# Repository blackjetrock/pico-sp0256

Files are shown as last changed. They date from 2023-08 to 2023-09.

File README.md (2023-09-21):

# Rp2040 Emulation of the SP0256-AL2 IC

Despite the name, this projects does not use the RP Pico. It is a PCB that has the footprint of the 28pin SP0256-AL2 IC. It plugs in to the same footprint as the IC and performs the functions that the IC does. Well, some of them:

1) Has allophones of the SP0256-AL2 as audio samples
2) Responds to the ALD signal falliung edge, latches the allophone nyumber and plays it.
3) Drives the LRQ line

It does not:
1) Handle an external ROM
2) Handle the play allohone on address line going to 1 mode.
   
This version of the code and PCB is designed to replace an SP0256-AL2 based psion organiser II speech adapter. It will need testing and adjusting in other uses.
It should be treated as a work in progress.

This project builds on the work of two other projects the first is here:

https://github.com/ExtremeElectronics/SP0256-AL2-Pico-Emulation-Detail

and contains code that drives the PWM to generate the audio from the phoneme data which is at this project:

https://www.cpcwiki.eu/index.php/SP0256_Allophones

These two projects have been combined and then added to in order to do the emulation of the SP0256 IC itself, such that it can be placed into the footprint of one of those ICs.

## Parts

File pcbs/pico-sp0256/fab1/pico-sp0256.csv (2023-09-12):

Id | Designator | Package | Quantity | Designation | Supplier and ref
1 | R4,R3 | R_0805_2012Metric | 2 | 27R
2 | Y1 | ecx-32 | 1 | ABLS-12.000MHZ-B4-T
3 | U1 | DIP-28_W15.24mm | 1 | SP0256AL2
4 | D2,D1 | D_SOD-123 | 2 | D_Small
5 | U5 | RP2040-QFN-56-no_holes | 1 | RP2040
6 | U3 | SOT-223-3_TabPin2 | 1 | NCP1117-3.3_SOT223
7 | U2 | SOIC-8_5.23x5.23mm_P1.27mm | 1 | W25Q128JVS
8 | R2 | C_0402_1005Metric | 1 | 10k
9 | R1 | C_0402_1005Metric | 1 | 1k
10 | J2 | PinHeader_1x03_P2.54mm_Vertical | 1 | Conn_01x03_Female
11 | J1 | USB_Micro-B_GCT_USB3076-30-A | 1 | USB_B_Micro
12 | C12,C11,C9,C7,C6,C3 | C_0402_1005Metric | 6 | 100n
13 | C10,C8 | C_0402_1005Metric | 2 | 1u
14 | C5,C4 | C_0805_2012Metric | 2 | 10u
15 | C2,C1 | C_0402_1005Metric | 2 | 27p

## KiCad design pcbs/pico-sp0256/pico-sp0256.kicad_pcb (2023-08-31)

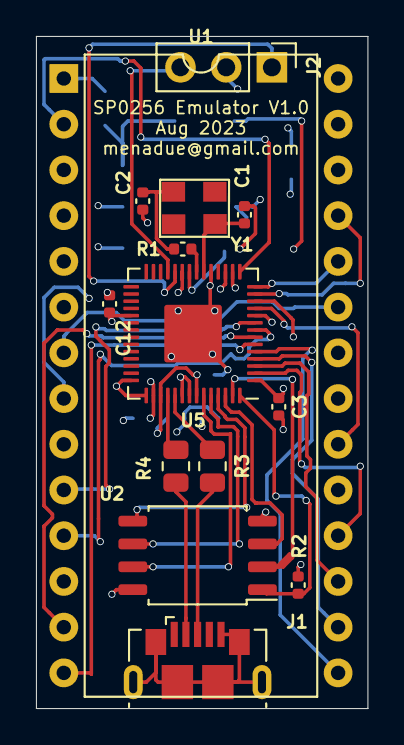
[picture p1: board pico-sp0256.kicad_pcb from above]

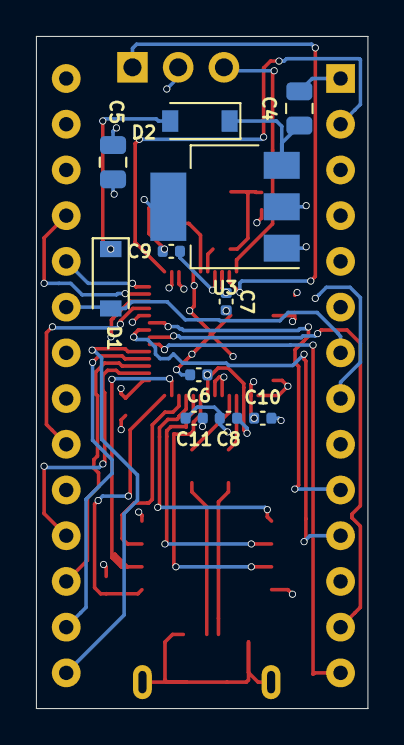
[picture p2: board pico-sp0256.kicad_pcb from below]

Board: 4 copper layers, 18.4 x 37.3 mm, 25 parts (11 on the bottom side), 36 nets.

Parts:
C1, C2: 27p; C_0402_1005Metric
C3, C6, C7, C9, C11, C12: 100n; C_0402_1005Metric
C4, C5: 10u; C_0805_2012Metric
C8, C10: 1u; C_0402_1005Metric
D1, D2: D_Small; D_SOD-123
J1: USB_B_Micro; USB_Micro-B_GCT_USB3076-30-A
J2: Conn_01x03_Female; PinHeader_1x03_P2.54mm_Vertical
R1: 1k; C_0402_1005Metric
R2: 10k; C_0402_1005Metric
R3, R4: 27R; R_0805_2012Metric
U1: SP0256AL2; DIP-28_W15.24mm
U2: W25Q128JVS; SOIC-8_5.23x5.23mm_P1.27mm
U3: NCP1117-3.3_SOT223; SOT-223-3_TabPin2
U5: RP2040; RP2040-QFN-56-no_holes
Y1: ABLS-12.000MHZ-B4-T; ecx-32

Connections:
+1V1: C6.1, C7.1, C8.1, U5.23, U5.45, U5.50
+3V3: C3.1, C5.1, C9.1, C10.1, C11.1, C12.1, R2.1, U2.8, U3.2, U5.1, U5.10, U5.22, U5.33, U5.42, U5.43, U5.44, U5.48, U5.49
GND: C1.2, C2.2, C3.2, C4.2, C5.2, C6.2, C7.2, C8.2, C9.2, C10.2, C11.2, C12.2, J1.5, J1.6, J2.2, U1.1, U2.4, U3.1, U5.19, U5.57
unnamed: C2.1, R1.2, Y1.2
unnamed: C4.1, D2.1, U3.3
unnamed: D1.1, D2.2
unnamed: J1.2, R4.2
unnamed: J1.3, R3.2
QSPI_SCLK: U2.6, U5.52
QSPI_SD0: U2.5, U5.53
QSPI_SD1: U2.2, U5.55
QSPI_SD2: U2.3, U5.54
QSPI_SD3: U2.7, U5.51
QSPI_SS: R2.2, U2.1, U5.56
SP_A1: U1.18, U5.2
SP_A2: U1.17, U5.3
SP_A3: U1.16, U5.4
SP_A4: U1.15, U5.5
SP_A5: U1.14, U5.6
SP_A6: U1.13, U5.7
SP_A7: U1.11, U5.8
SP_A8: U1.10, U5.9
SP_ALD: U1.20, U5.11
SP_DIGITAL_OUT: U1.24, U5.14
SP_LRQ_N: U1.9, U5.16
SP_RESET_N: U1.2, U5.15
SP_SBY: U1.8, U5.17
SP_SBY_RES_N: U1.25, U5.13
SP_SE: U1.19, U5.12
SWCLK: J2.1, U5.24
SWD: J2.3, U5.25
USB_DM: R4.1, U5.46
USB_DP: R3.1, U5.47
VDD: D1.2, U1.7, U1.23
XIN: C1.1, U5.20, Y1.1
XOUT: R1.1, U5.21

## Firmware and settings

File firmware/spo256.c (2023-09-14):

/**
 * SPO256 -AL2 
 * samples from https://www.cpcwiki.eu/index.php/SP0256_Allophones
 * 
 * Pico code Derek Woodroffe 4/5/2022
 *
 */

//pico SDK includes
#include <stdio.h>
#include "pico/stdlib.h"
#include "hardware/pwm.h"
#include "pico/multicore.h"

//program includes
#include "allophones.c"
#include "allophoneDefs.h"

//must be pins on the same slice
#define soundIO1 11
#define soundIO2 12

#define PIN_SP_A1            0
#define PIN_SP_A2            1
#define PIN_SP_A3            2
#define PIN_SP_A4            3
#define PIN_SP_A5            4
#define PIN_SP_A6            5
#define PIN_SP_A7            6
#define PIN_SP_A8            7
#define PIN_SP_ALD           8
#define PIN_SP_SE            9
#define PIN_SP_SBY_RES_N    10
#define PIN_SP_DIGITAL_OUT  11
#define PIN_SP_RESET_N      12
#define PIN_SP_LRQ_N        13
#define PIN_SP_SBY          14


#define rate 90

uint PWMslice;

void PlayAllophone(int al)
{
  int b,s;
  uint8_t v;
  
  s=allophonesizeCorrected[al];
  //printf("\nstart %d", s);
  
  for(b=0;b<s;b++)
    {
      v=allophoneindex[al][b]; //get delta value
      //printf("\n%d", v);
      
      pwm_set_both_levels(PWMslice,v,v);
      volatile int x;

      for(x=0; x<125*9; x++)
	{
	}
      
      //sleep_us(rate);
      //sleep_ms(2);
    }

  //printf("\nend");
}

void PlayAllophones(uint8_t *alist,int listlength)
{
  int a;

  printf("\nStart allophones");
  for(a=0; a<listlength; a++)
    {
      PlayAllophone(alist[a]);
    }

  pwm_set_both_levels(PWMslice, 0x0, 0x0);
}

void SetPWM(void)
{
  gpio_init(soundIO1);
  gpio_set_dir(soundIO1,GPIO_OUT);
  gpio_set_function(soundIO1, GPIO_FUNC_PWM);
  
  //  gpio_init(soundIO2);
  //gpio_set_dir(soundIO2,GPIO_OUT);
  //gpio_set_function(soundIO2, GPIO_FUNC_PWM);
  
  PWMslice=pwm_gpio_to_slice_num (soundIO1);
  
  pwm_set_clkdiv(PWMslice,16);
  pwm_set_both_levels(PWMslice,0x80,0x80);
  
  pwm_set_output_polarity(PWMslice,true,false);
  
  pwm_set_wrap (PWMslice, 256);
  pwm_set_enabled(PWMslice,true);
  
}

void test_gpios(void)
{
  gpio_init(soundIO1);
  gpio_set_dir(soundIO1,GPIO_OUT);

  while(1)
    {
      gpio_put(soundIO1, 0);
      sleep_ms(2);
      gpio_put(soundIO1, 1);
      sleep_ms(2);
      
    }
  

}

void test_gpios2(void)
{
  SetPWM();
  
  while(1)
    {
      pwm_set_both_levels(PWMslice,0x10,0x10);
      //      gpio_put(soundIO1, 0);
      sleep_ms(2);
      pwm_set_both_levels(PWMslice,0xA0,0xA0);
      //gpio_put(soundIO1, 1);
      sleep_ms(2);
      
    }
}

void core1_main(void)
{
  uint8_t alist[] ={AR,PA5,PP,EH,IY,PA5,TT2,WH,EH,EH,NN1,PA2,PA3,TT2,IY,PA5,FF,OR,PA3,TT2,IY,PA5};

  //  printf("\nCore1 started");

  int last_ald = gpio_get(PIN_SP_ALD);
  int ald;

  //  irq_set_mask_enabled(0xffffffff, false);

      
  while(0)
    {
      printf("\nPlaying %d", sizeof(alist));
      
      PlayAllophones(alist,sizeof(alist));


    }

  while(1)
    {
      // Sit in loop waiting for allophone selection
      ald = gpio_get(PIN_SP_ALD);

      if( (ald == 0) && (last_ald == 1) )
	{
	  //	  printf("\nNeg edge");

	  // When we get a neg edge we lath the address lines in
	  int gpio_states = (sio_hw->gpio_in) & 0x3F;

	  //printf("\nAllophone %d", gpio_states);

	  gpio_put(PIN_SP_LRQ_N, 1);
	  gpio_put(PIN_SP_SBY, 0);

	  PlayAllophone(gpio_states);
	  
	  gpio_put(PIN_SP_LRQ_N, 0);
	  gpio_put(PIN_SP_SBY, 1);
	}

      last_ald = ald;
    }

  while(1)
    {
      printf("\nPlaying %d", sizeof(alist));
      
      PlayAllophones(alist,sizeof(alist));

      sleep_ms(3000);

    }
}

void set_gpio_input(int gpio)
{
  gpio_init(gpio);
  gpio_set_dir(gpio, GPIO_IN);
}

int main()
{
  ////////////////////////////////////////////////////////////////////////////////
  //
  // Overclock as needed
  //
  ////////////////////////////////////////////////////////////////////////////////
#if 0  
  #define OVERCLOCK 135000
  //#define OVERCLOCK 200000
  //#define OVERCLOCK 270000
  //#define OVERCLOCK 360000
  
#if OVERCLOCK > 270000
  /* Above this speed needs increased voltage */
  vreg_set_voltage(VREG_VOLTAGE_1_20);
  sleep_ms(1000);
#endif

  
  /* Overclock */
  set_sys_clock_khz( OVERCLOCK, 1 );
#endif
  
  stdio_init_all();
  //  sleep_ms(2000);

  printf("\n*********************");
  printf("\n*  SP0256 Emulator  *");
  printf("\n*********************");
  
  set_gpio_input(PIN_SP_A1);
  set_gpio_input(PIN_SP_A2);
  set_gpio_input(PIN_SP_A3);
  set_gpio_input(PIN_SP_A4);
  set_gpio_input(PIN_SP_A5);
  set_gpio_input(PIN_SP_A6);
  set_gpio_input(PIN_SP_A7);
  set_gpio_input(PIN_SP_A8);
  
  
  gpio_init(PIN_SP_LRQ_N);
  gpio_set_dir(PIN_SP_LRQ_N, GPIO_OUT);
  gpio_put(PIN_SP_LRQ_N, 0);

  gpio_init(PIN_SP_SBY);
  gpio_set_dir(PIN_SP_SBY, GPIO_OUT);
  gpio_put(PIN_SP_SBY, 1);
  
  SetPWM();
  //test_gpios2();
  
  uint8_t alist[] ={HH,EH,LL,AX,OW,PA5,WW,OR,LL,DD1};

#if 1
  multicore_launch_core1(core1_main);
#else
    
  while(1)
    {
      printf("\nPlaying %d", sizeof(alist));
      
      PlayAllophones(alist,sizeof(alist));

      sleep_ms(3000);

    }
  
#endif
  while(1)
    {
    }
  
}
